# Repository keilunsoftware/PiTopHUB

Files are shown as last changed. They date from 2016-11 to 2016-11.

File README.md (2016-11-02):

# PiTopHUB
PiTop addon board with Arduino ATMEGA328P programming and breakout

Features:

- USB Hub with 2 free ports and WDPi usb (WDPi can be installed on top of PiTop power hub)
- Full Arduino compatible breakout board (programmable from RPi)
- PiTop 16-18V power connector
- Full RPi GPIO connector (removed permanent 3v3 pin to avoid battery drain, even when off)
- Pin connector for TinyRTC module (battery on top)

Known issues:

- With permanent USB devices connected to RPi USB PiTop experiences a battery drain even when powered off. Need to add an additional switch on the RPi USB power cable

Order PCB directly from OSH Park: https://oshpark.com/shared_projects/OJJPJsZg

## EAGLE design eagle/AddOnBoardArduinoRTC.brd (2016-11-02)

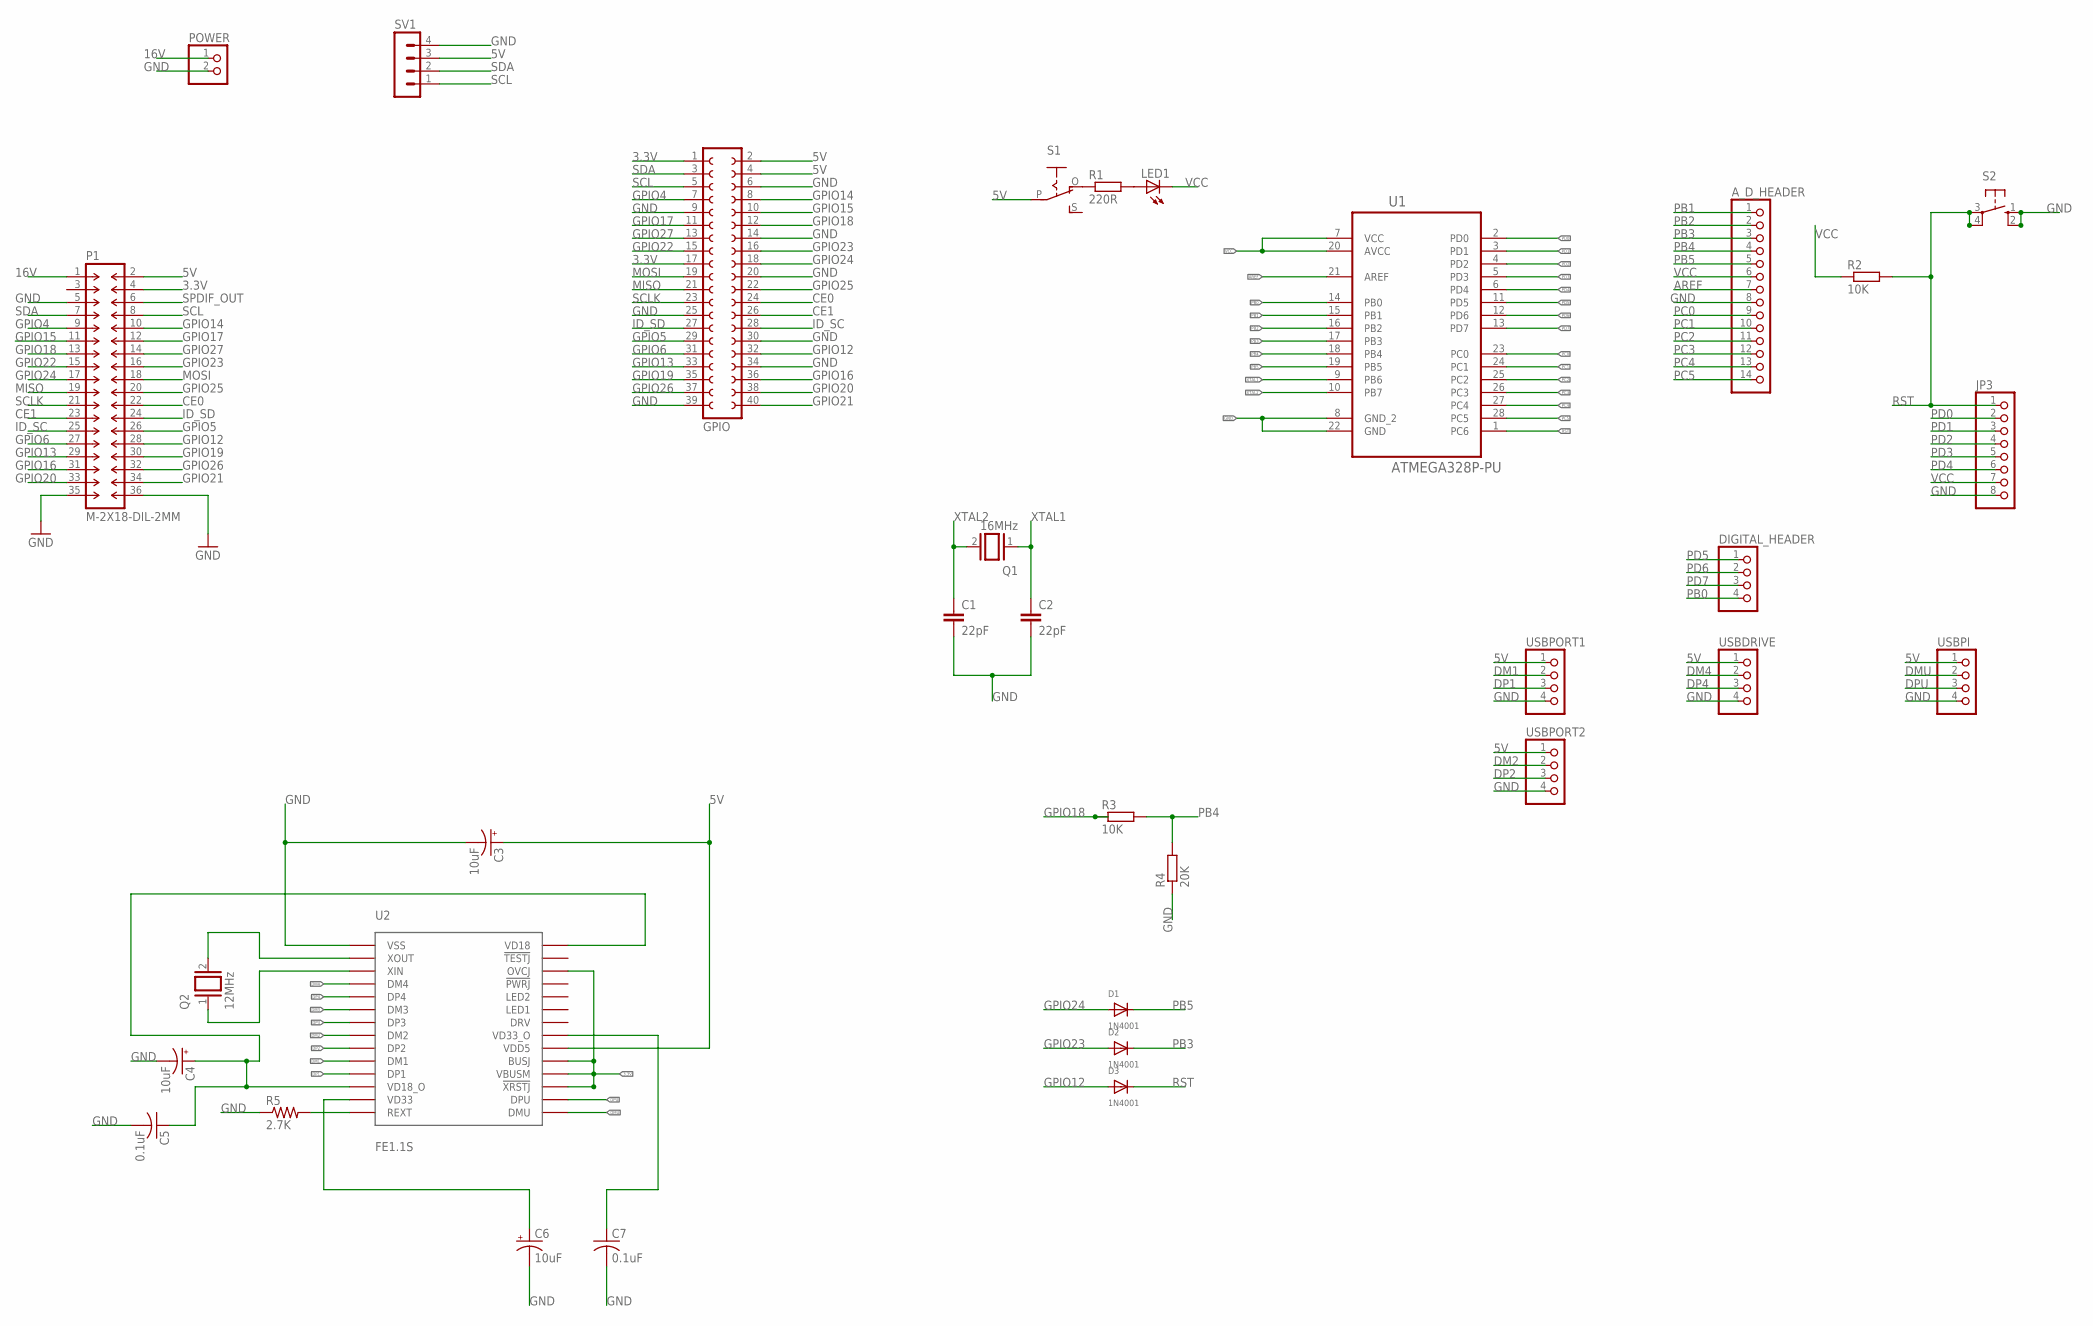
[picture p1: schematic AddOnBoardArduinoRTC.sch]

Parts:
A_D_HEADER: PINHD-1X14; 1X14
C1, C2: 22pF; C025-024X044
C3, C4, C6: 10uF; 153CLV-0605
C5, C7: 0.1uF; C1206
D1, D2, D3: 1N4001; SMADIODE
DIGITAL_HEADER: PINHD-1X4; 1X04
GPIO: FE20-2
JP3: PINHD-1X8; 1X08
LED1: LED5MM
P1: M-2X18-DIL-2MM; DIL-2MM-2X18
POWER: PINHD-1X2; 1X02
Q1: 16MHz; QS
Q2: 12MHz; QS
R1: 220R; M1206
R2, R3: 10K; M1206
R4: 20K; M1206
R5: 2.7K; M1206
S1: EG1218S; EG1218
S2: 10-XX; B3F-10XX
SV1: MA04-1
U1: ATMEGA328P-PU; DIP254P762X457-28
U2: FE1.1S; SSOP-28
USBDRIVE: PINHD-1X4; 1X04
USBPI: PINHD-1X4; 1X04
USBPORT1, USBPORT2: PINHD-1X4; 1X04

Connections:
3.3V: GPIO.1, GPIO.17, P1.4, U2.17 (!XRSTJ), U2.18 (VBUSM), U2.19 (BUSJ), U2.26 (OVCJ)
5V: C3.+, GPIO.2, GPIO.4, P1.2, S1.P, SV1.3, U2.20 (VDD5), USBDRIVE.1, USBPI.1, USBPORT1.1, USBPORT2.1
16V: P1.1, POWER.1
AREF: A_D_HEADER.7, U1.21 (AREF)
CE0: GPIO.24, P1.22
CE1: GPIO.26, P1.23
DM1: U2.10 (DM1), USBPORT1.2
DM2: U2.8 (DM2), USBPORT2.2
DM3: U2.6 (DM3)
DM4: U2.4 (DM4), USBDRIVE.2
DMU: U2.15 (DMU), USBPI.2
DP1: U2.11 (DP1), USBPORT1.3
DP2: U2.9 (DP2), USBPORT2.3
DP3: U2.7 (DP3)
DP4: U2.5 (DP4), USBDRIVE.3
DPU: U2.16 (DPU), USBPI.3
GND: A_D_HEADER.8, C1.2, C2.2, C3.-, C4.-, C5.2, C6.-, C7.2, GPIO.6, GPIO.9, GPIO.14, GPIO.20, GPIO.25, GPIO.30, GPIO.34, GPIO.39, JP3.8, P1.5, P1.35, P1.36, POWER.2, R4.1, R5.1, S2.1 (S), S2.2 (S1), SV1.4, U1.8 (GND_2), U1.22 (GND), U2.1 (VSS), USBDRIVE.4, USBPI.4, USBPORT1.4, USBPORT2.4
GPIO4: GPIO.7, P1.9
GPIO5: GPIO.29, P1.26
GPIO6: GPIO.31, P1.27
GPIO12: D3.A, GPIO.32, P1.28
GPIO13: GPIO.33, P1.29
GPIO14: GPIO.8, P1.10
GPIO15: GPIO.10, P1.11
GPIO16: GPIO.36, P1.31
GPIO17: GPIO.11, P1.12
GPIO18: GPIO.12, P1.13, R3.1
GPIO19: GPIO.35, P1.30
GPIO20: GPIO.38, P1.33
GPIO21: GPIO.40, P1.34
GPIO22: GPIO.15, P1.15
GPIO23: D2.A, GPIO.16, P1.16
GPIO24: D1.A, GPIO.18, P1.17
GPIO25: GPIO.22, P1.20
GPIO26: GPIO.37, P1.32
GPIO27: GPIO.13, P1.14
ID_SC: GPIO.28, P1.25
ID_SD: GPIO.27, P1.24
MISO: GPIO.21, P1.19
MOSI: GPIO.19, P1.18
unnamed: Q2.2, U2.2 (XOUT)
unnamed: Q2.1, U2.3 (XIN)
unnamed: R5.2, U2.14 (REXT)
unnamed: C6.+, U2.13 (VD33)
unnamed: C4.+, C5.1, U2.12 (VD18_O), U2.28 (VD18)
unnamed: C7.1, U2.21 (VD33_O)
unnamed: R1.1, S1.O
unnamed: LED1.A, R1.2
PB0: DIGITAL_HEADER.4, U1.14 (PB0)
PB1: A_D_HEADER.1, U1.15 (PB1)
PB2: A_D_HEADER.2, U1.16 (PB2)
PB3: A_D_HEADER.3, D2.C, U1.17 (PB3)
PB4: A_D_HEADER.4, R3.2, R4.2, U1.18 (PB4)
PB5: A_D_HEADER.5, D1.C, U1.19 (PB5)
PC0: A_D_HEADER.9, U1.23 (PC0)
PC1: A_D_HEADER.10, U1.24 (PC1)
PC2: A_D_HEADER.11, U1.25 (PC2)
PC3: A_D_HEADER.12, U1.26 (PC3)
PC4: A_D_HEADER.13, U1.27 (PC4)
PC5: A_D_HEADER.14, U1.28 (PC5)
PD0: JP3.2, U1.2 (PD0)
PD1: JP3.3, U1.3 (PD1)
PD2: JP3.4, U1.4 (PD2)
PD3: JP3.5, U1.5 (PD3)
PD4: JP3.6, U1.6 (PD4)
PD5: DIGITAL_HEADER.1, U1.11 (PD5)
PD6: DIGITAL_HEADER.2, U1.12 (PD6)
PD7: DIGITAL_HEADER.3, U1.13 (PD7)
RST: D3.C, JP3.1, R2.2, S2.3, S2.4 (P1), U1.1 (PC6)
SCL: GPIO.5, P1.8, SV1.1
SCLK: GPIO.23, P1.21
SDA: GPIO.3, P1.7, SV1.2
SPDIF_OUT: P1.6
VCC: A_D_HEADER.6, JP3.7, LED1.K (C), R2.1, U1.7 (VCC), U1.20 (AVCC)
XTAL1: C2.1, Q1.1, U1.9 (PB6)
XTAL2: C1.1, Q1.2, U1.10 (PB7)

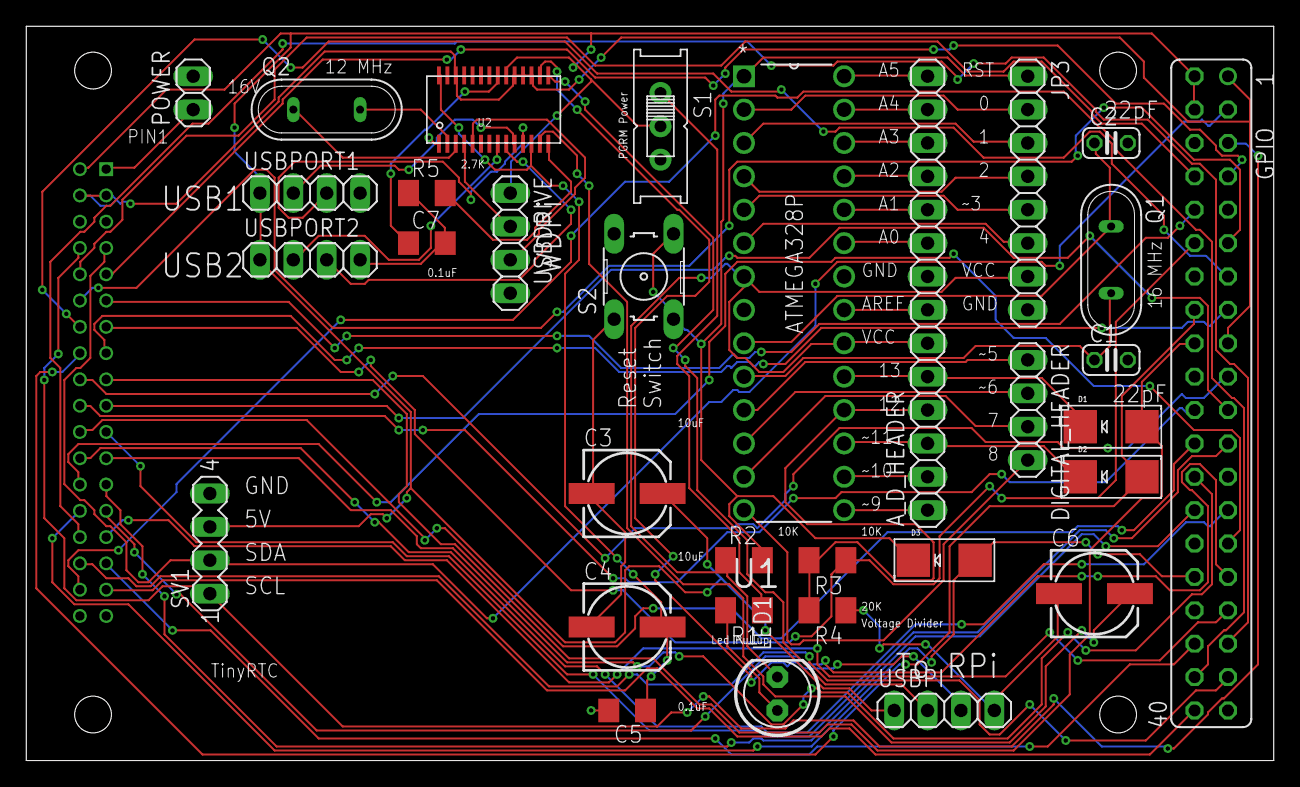
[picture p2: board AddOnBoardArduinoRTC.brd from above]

Board: 2 copper layers, 94.9 x 55.9 mm, 33 parts (1 on the bottom side), 73 nets.

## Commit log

2016-11-02 Added Eagle Schematics and Board layout
    [AddOnBoardArduinoRTC.brd, AddOnBoardArduinoRTC.sch]
2016-11-02 Added OSH Park Direct PCB order link

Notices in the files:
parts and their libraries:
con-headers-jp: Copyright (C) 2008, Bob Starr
